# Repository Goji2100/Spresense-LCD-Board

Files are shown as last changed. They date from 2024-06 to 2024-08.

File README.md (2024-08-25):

# Spresense-LCD-Board
## LCD board for Spresense
Spresenseの拡張ボードにスタックするLCDボードです
<br>

## 表示画面
<table>
<tr>
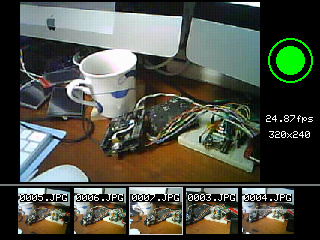
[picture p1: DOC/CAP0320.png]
<td></td>
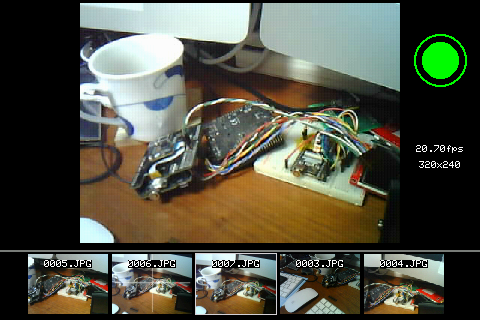
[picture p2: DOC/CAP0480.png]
<td></td>
</tr>
<tr>
<td>表示画面（480 x 320）</td>
<td>表示画面（320 x 240）</td>
</tr>
</table>
<br>

## 組み立て完成写真
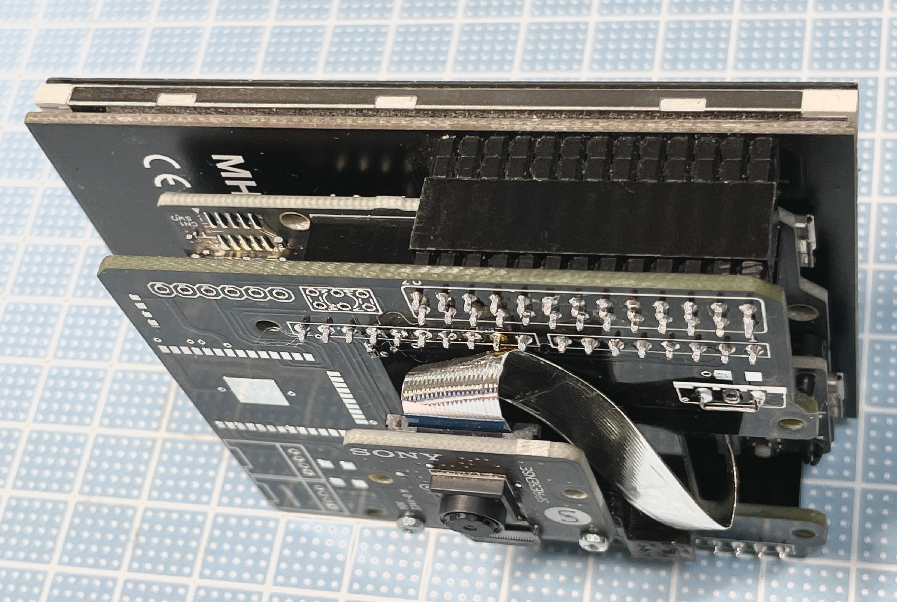
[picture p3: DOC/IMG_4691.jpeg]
<br><br>

## LCDボードとSpresense拡張ボード
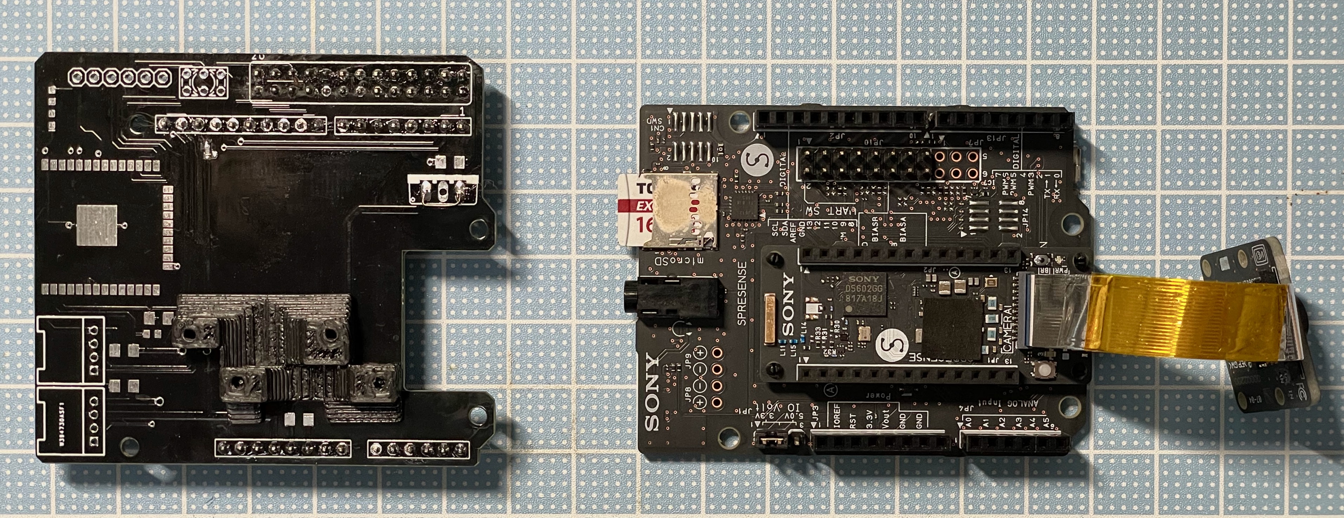
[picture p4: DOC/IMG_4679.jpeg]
<br><br>

## LCDボード回路図
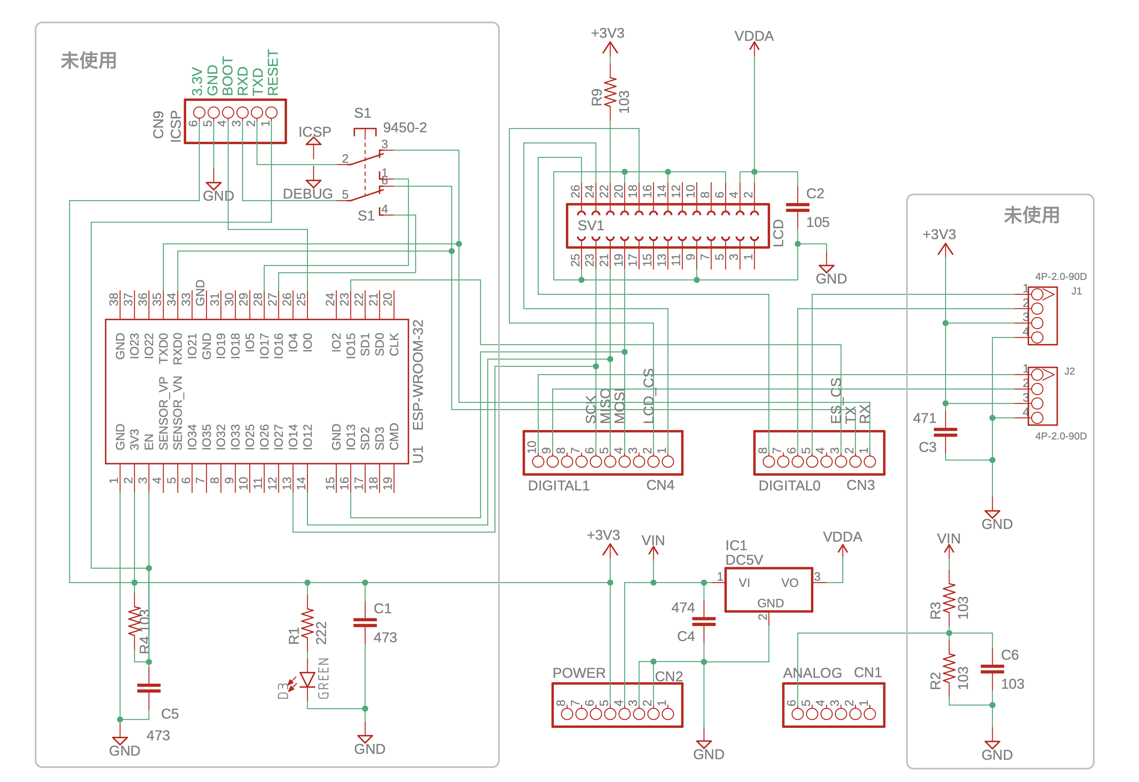
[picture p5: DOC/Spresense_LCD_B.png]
<br><br>

## 使用するLCD


左）3.5 インチタッチスクリーン MHS TFT LCD モジュール[SPI 125MHz Support]<br>
右）GeeekPi 3.5インチ320 * 480モニタータッチパネル LCD[SPI 180MHz Support]　　
<br>
<br>
<br>

## その他のLCD
<table>
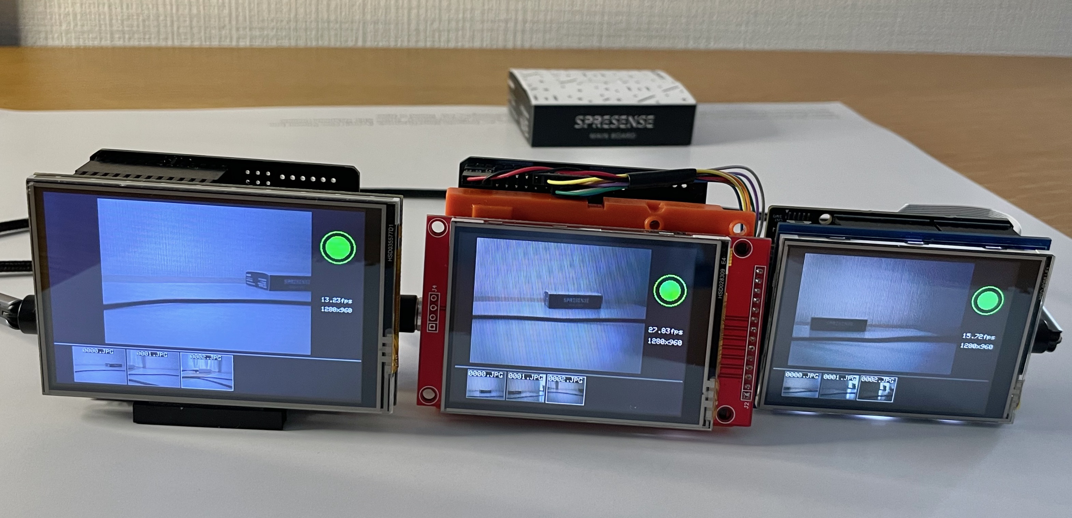
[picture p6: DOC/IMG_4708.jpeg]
<tr><td></td></tr>
</table>
<br>

### Adafruit ILI9341
<table>
<tr>
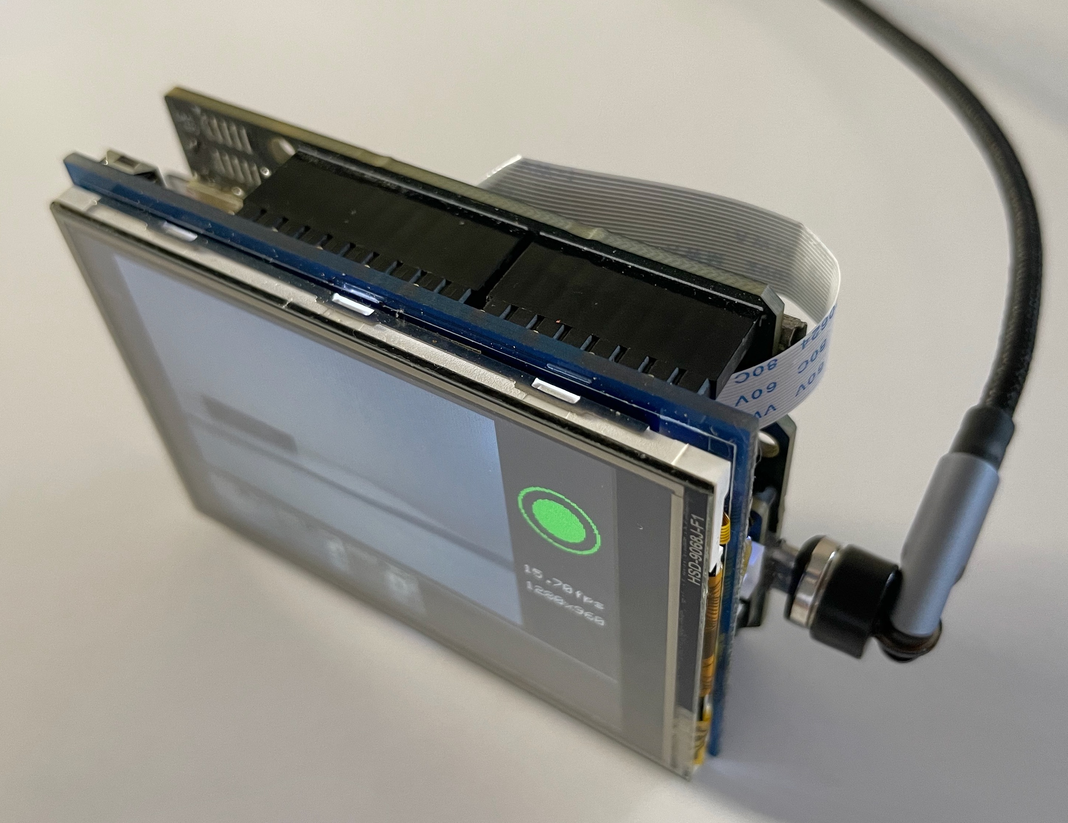
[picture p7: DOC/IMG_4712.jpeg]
<td></td>
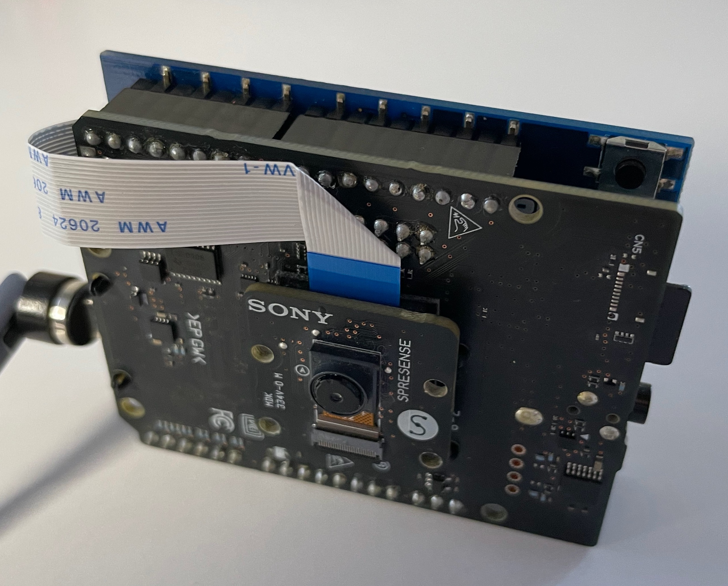
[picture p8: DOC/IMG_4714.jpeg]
<td></td>
</tr>
<tr>
<td>Adafruit ILI9341（表面） 320 x 240</td>
<td>Adafruit ILI9341（背面）</td>
</tr>
</table>

### Adafruit ILI9341 の組み込み
<table>
<tr>
<td></td>
</tr>
<tr>
<td>フラットケーブルの折り曲げ加工、ILI9341の改造（TFT_CSをpin6に変更する）</td>
</tr>
</table>
<table>
<tr>
<td></td>
</tr>
<tr>
<td>フラットケーブル取り付け、動作電圧の変更（Shieldは５V動作）</td>
</tr>
</table>
<table>
<tr>
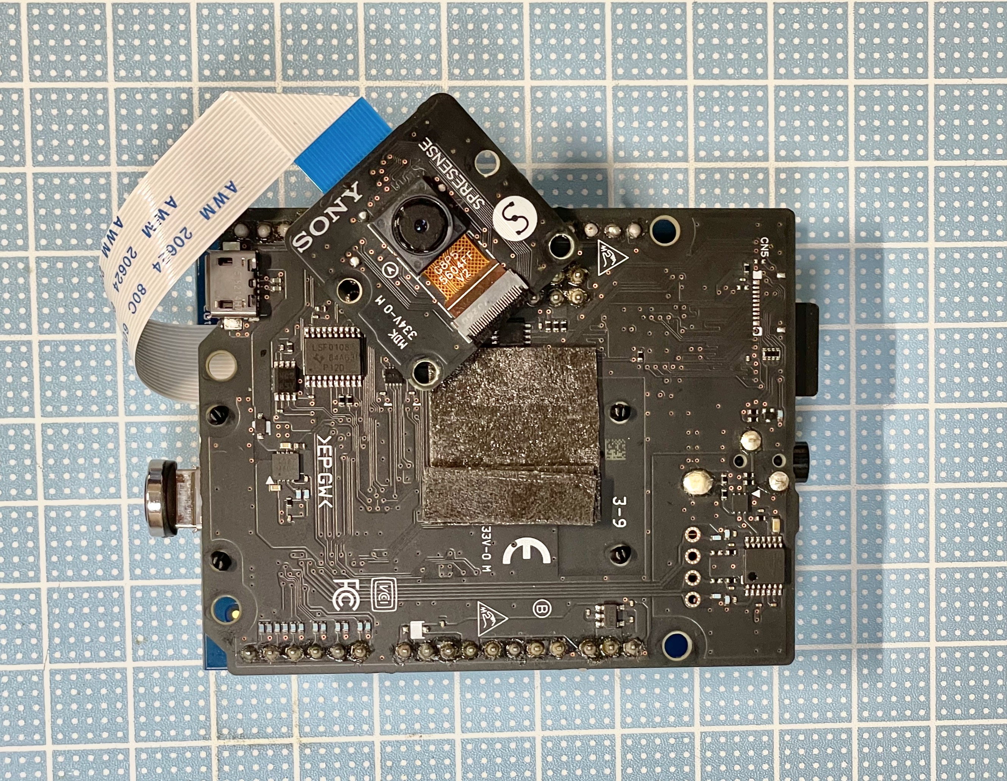
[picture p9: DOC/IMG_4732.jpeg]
<td></td>
</tr>
<tr>
<td>カメラは拡張ボードの背面に両面テープで貼り付け💦</td>
</tr>
</table>
<br>

### ILI9341(320 x 240)/ILI9488(480 x 320)
<table>
<tr>
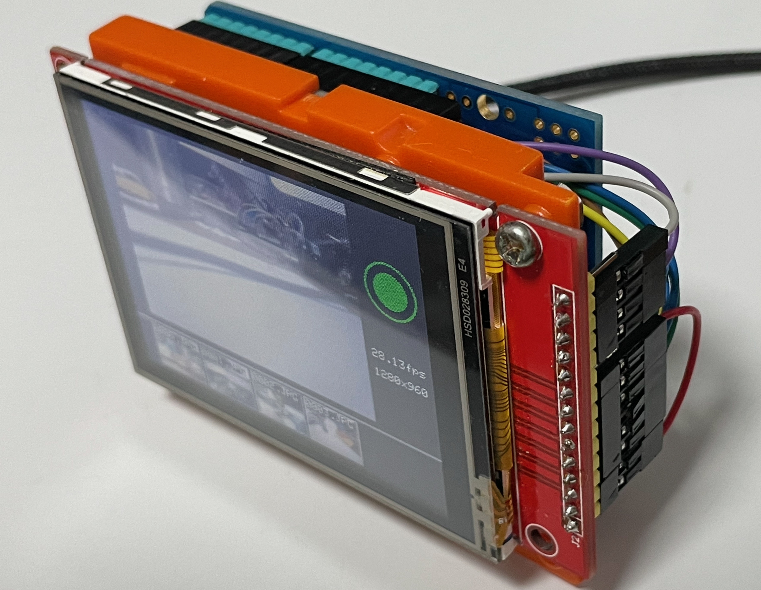
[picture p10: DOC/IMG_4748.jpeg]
<td></td>
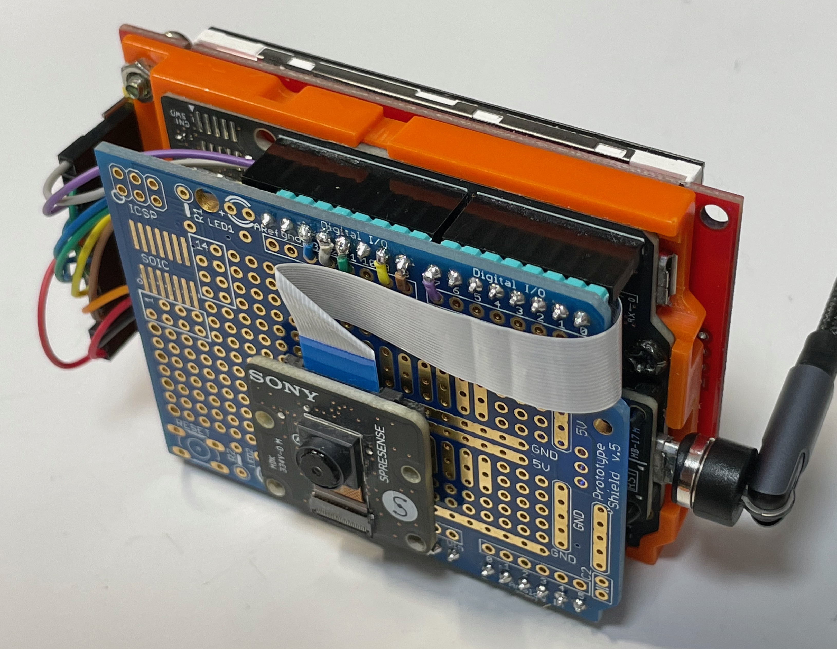
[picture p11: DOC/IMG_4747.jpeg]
<td></td>
</tr>
<tr>
<td>ILI9341（表面） 320 x 240</td>
<td>ILI9341（背面）</td>
</tr>
</table>
<br>

### ILI9341/ILI9488 の組み込み
<table>
<tr>
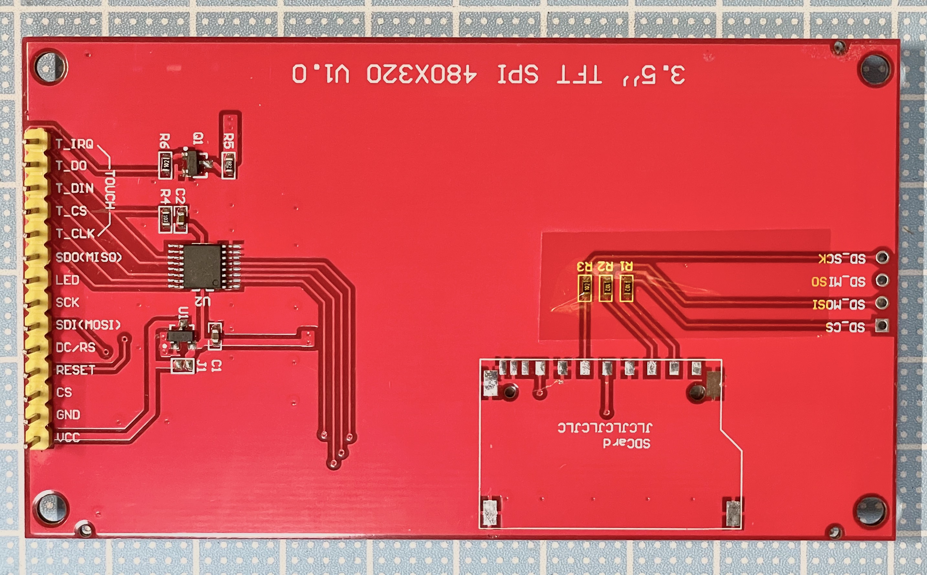
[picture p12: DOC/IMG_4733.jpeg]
<td></td>
<td></td>
</tr>
<tr>
<td>ILI9488（ILI9341とピン配置は同じ）</td>
<td>ILI9341/ILI9488と拡張ボードとの配線</td>
</tr>
</table>
<br>

<table>
<tr>
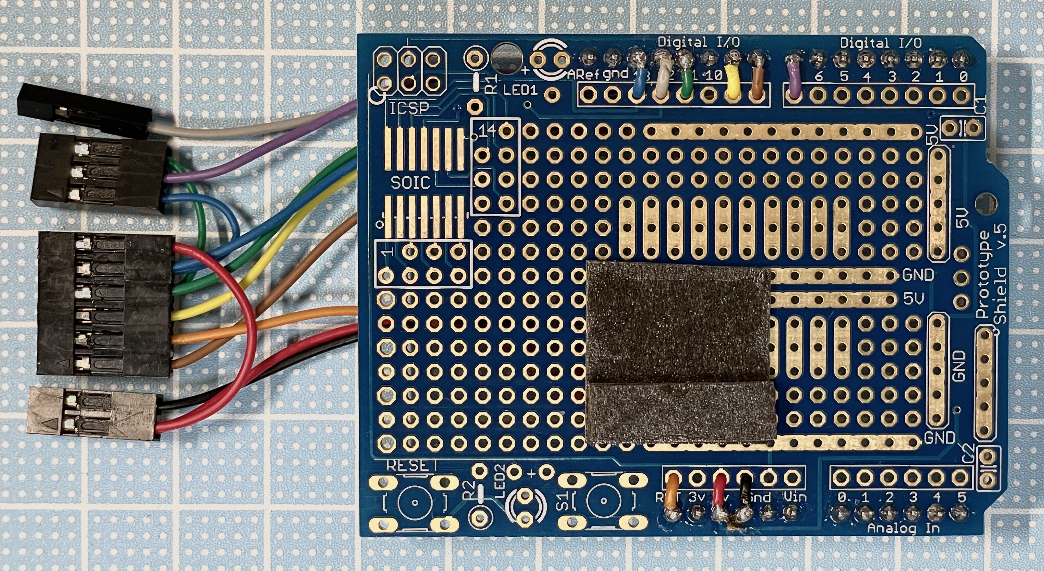
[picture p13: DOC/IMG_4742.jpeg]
<td></td>
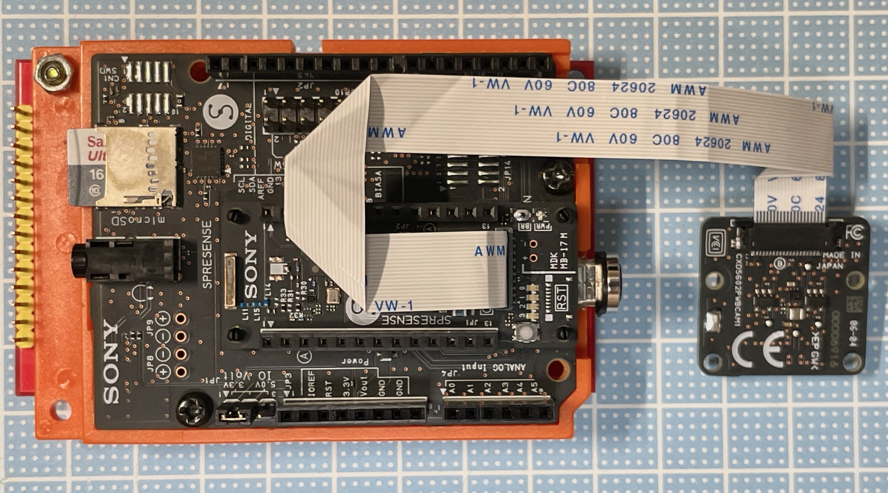
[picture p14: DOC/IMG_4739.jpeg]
<td></td>
</tr>
<tr>
<td>実際の配線（ProtoType Shieldを経由します）</td>
<td>カメラフラットケーブルの折り曲げ加工</td>
</tr>
</table>
<br>

### ILI9486(480 x 320)
<table>
<tr>
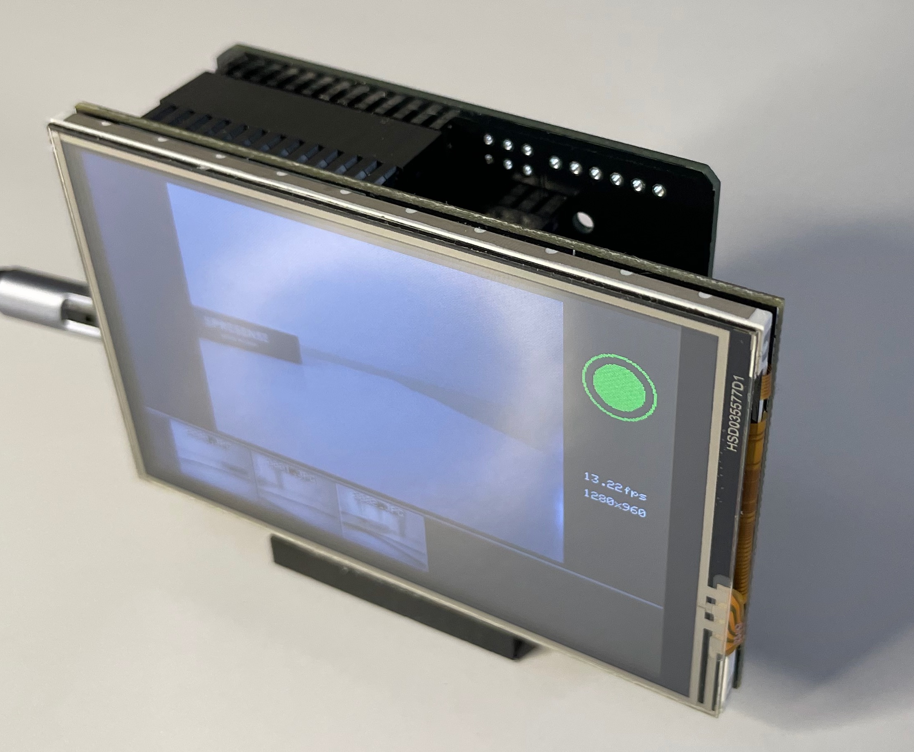
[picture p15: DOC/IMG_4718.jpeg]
<td></td>
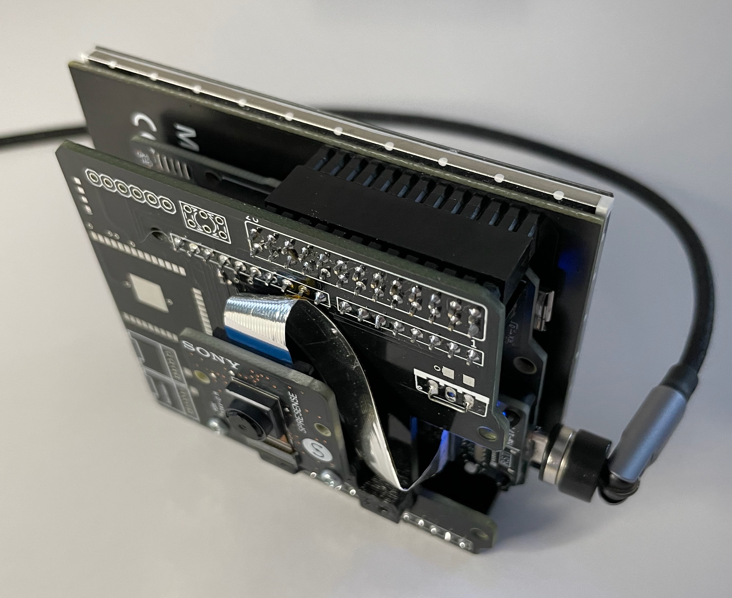
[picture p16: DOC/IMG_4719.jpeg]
<td></td>
</tr>
<tr>
<td>ILI9486（表面） 480 x 320</td>
<td>ILI9486（裏面）</td>
</tr>
</table>
<br>

## ILI9486の組み込み
### - ピンヘッダー５組
### - プルアップ抵抗（10kΩ）
### - 電源シュートジャンパーを半田付け
### - カメラをカメラマウンターに取り付け<br><br>
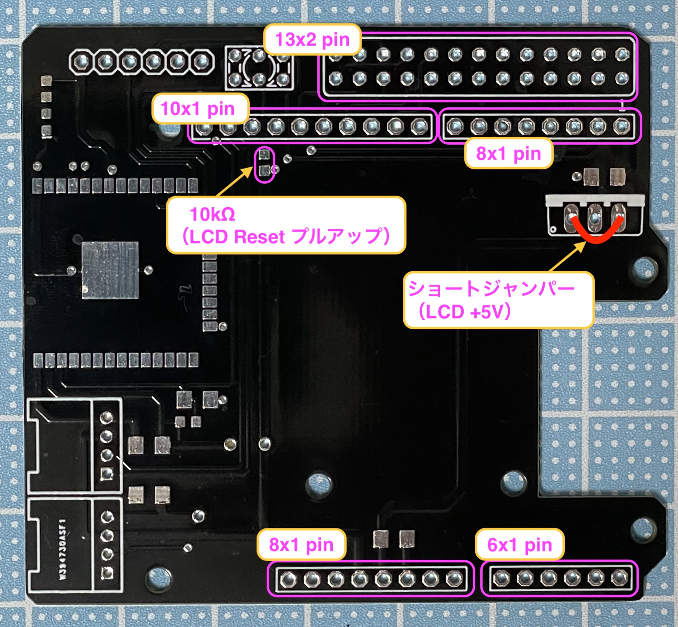
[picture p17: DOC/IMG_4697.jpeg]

<br>
<br>

### カメラマウンター<br>
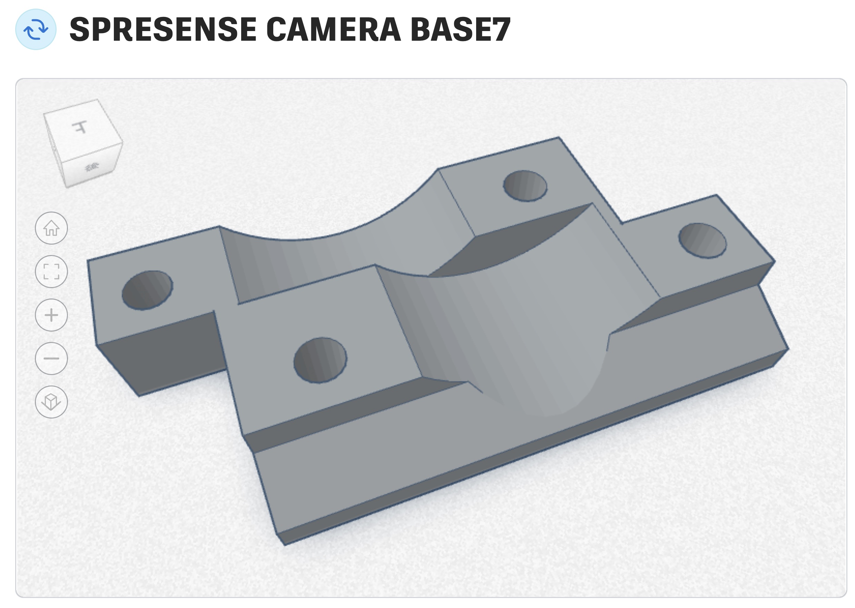
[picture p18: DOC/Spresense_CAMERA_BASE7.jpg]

#### [カメラマウンター] DOC/SPRESENSE CAMERA BASE7.stl <br>
#### [カメラマウンター　Tinkercad](https://www.tinkercad.com/things/2FAODkR43Zt-spresense-camera-base7)
<br><br>

## ビルド
1. フォルダ（camera_apitest）をArduinoスケッチフォルダーにコピー
2. ボードパッケージは "2.6.0" を使用します（3.xでは問題あり）
3. Memory:1536KBを選択
4. ライブラリーに "LovyanGFX(1.1.9)" と "XPT2046_Touchscreen" をインストール
5. Adafruit ILI9341のタッチパネルを使用する場合は "Adafruit_STMPE610" もインストール
6. ビルドしてアップロード

### define 文の変更（使用するLCDを選択）
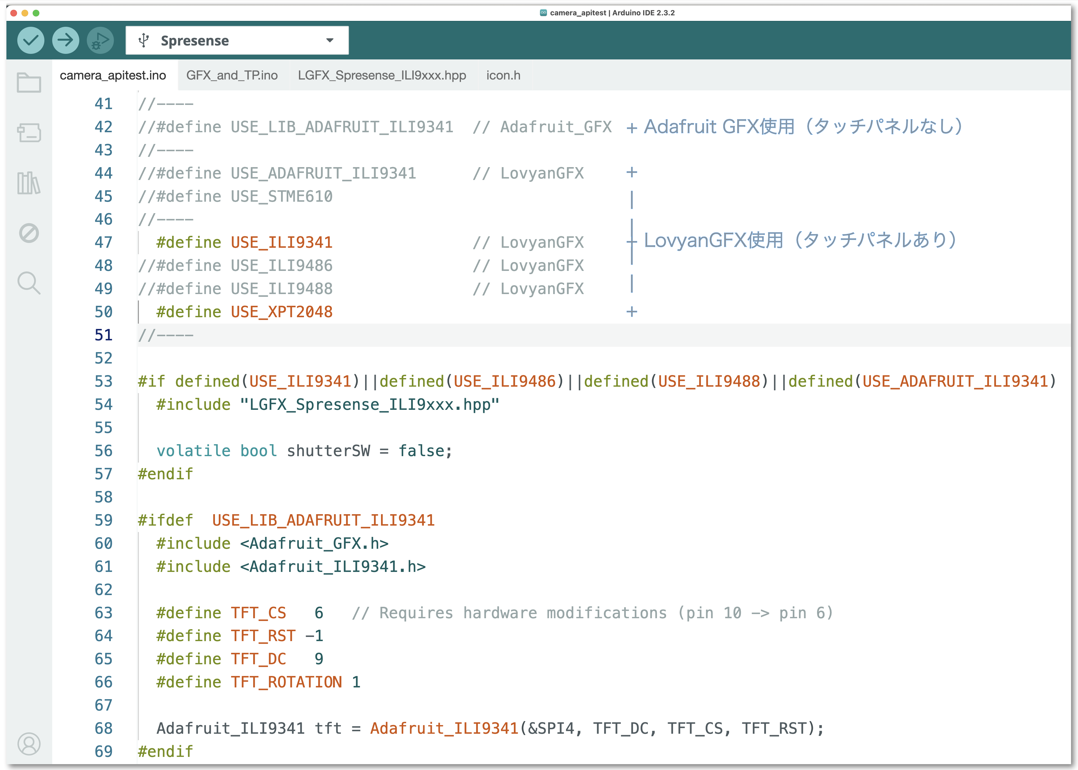
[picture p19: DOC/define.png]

<br><br>

## 使用方法
- オリジナルはSpresenseのサンプルスケッチ->camera->camera_apitest.inoです<br>
  LovyanGFXでプレビュー表示するする処理を追加<br>
  タッチパネル読み取り処理を追加<br>
  オリジナルにあるSerialターミナルでのメニュー操作はそのままです<br>
  （写真の解像度、ISO感度などの設定、撮影画像のSDへの保存などができます）<br>
- タッチパネルによる写真撮影処理を追加
- 撮影した写真のサムネイル表示処理を追加（最新の5枚まで表示）
<br><br>
## ライセンス
[LovyanGFX](https://github.com/lovyan03/LovyanGFX/tree/master) [FreeBSD](https://github.com/lovyan03/LovyanGFX/blob/master/license.txt) lovyan03
<br>
[camera_apitest.ino]() [GNU]() Sony Semiconductor Solutions Corporation
<br>

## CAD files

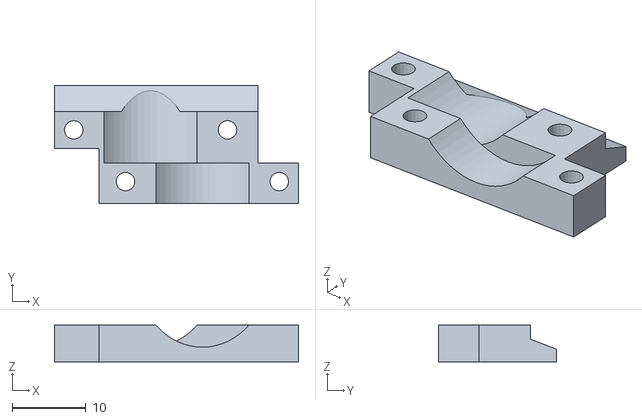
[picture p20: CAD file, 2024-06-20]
DOC/SPRESENSE CAMERA BASE7.stl
33.0 x 15.9 x 5.00

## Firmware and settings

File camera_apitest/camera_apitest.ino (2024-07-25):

/*
 *  camera_apitest.ino - Advanced camera API example sketch
 *  Copyright 2022 Sony Semiconductor Solutions Corporation
 *
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
 *  This is a test app for the camera library.
 *  This library can only be used on the Spresense with the FCBGA chip package.
 */

/****************************************************************************
 * Included Files
 ****************************************************************************/

#include <Camera.h>
#include <SDHCI.h>
#include <RTC.h>


/****************************************************************************
 * LCD preview option
 ****************************************************************************/

/* Use Adafruit_ILI9341 library and Adafruit-GFX-Library
 * Please see Spresense Arduino Tutorial for more details.
 * https://developer.sony.com/develop/spresense/docs/arduino_tutorials_ja.html
 */

//----
//#define USE_LIB_ADAFRUIT_ILI9341  // Adafruit_GFX
//----
//#define USE_ADAFRUIT_ILI9341      // LovyanGFX
//#define USE_STME610
//----
  #define USE_ILI9341               // LovyanGFX
//#define USE_ILI9486               // LovyanGFX
//#define USE_ILI9488               // LovyanGFX
  #define USE_XPT2048
//----

#if defined(USE_ILI9341)||defined(USE_ILI9486)||defined(USE_ILI9488)||defined(USE_ADAFRUIT_ILI9341) 
  #include "LGFX_Spresense_ILI9xxx.hpp"

  volatile bool shutterSW = false;
#endif

#ifdef  USE_LIB_ADAFRUIT_ILI9341
  #include <Adafruit_GFX.h>
  #include <Adafruit_ILI9341.h>

  #define TFT_CS   6   // Requires hardware modifications (pin 10 -> pin 6)
  #define TFT_RST -1
  #define TFT_DC   9
  #define TFT_ROTATION 1

  Adafruit_ILI9341 tft = Adafruit_ILI9341(&SPI4, TFT_DC, TFT_CS, TFT_RST);
#endif

/****************************************************************************
 * Initial parameters
 ****************************************************************************/
SDClass  theSD;
int               g_pict_id = 0;
int               g_width   = CAM_IMGSIZE_QUADVGA_H;
int               g_height  = CAM_IMGSIZE_QUADVGA_V;
CAM_IMAGE_PIX_FMT g_img_fmt = CAM_IMAGE_PIX_FMT_JPG;
CAM_WHITE_BALANCE g_wb      = CAM_WHITE_BALANCE_AUTO;
CAM_COLOR_FX      g_cfx     = CAM_COLOR_FX_NONE;
bool              g_awb     = true;
bool              g_ae      = true;
int               g_divisor = 7;

/****************************************************************************
 * Print error message
 ****************************************************************************/
void printError(enum CamErr err)
{
  Serial.print("Error: ");
  switch (err) {
  case CAM_ERR_NO_DEVICE:             Serial.println("No Device");                     break;
  case CAM_ERR_ILLEGAL_DEVERR:        Serial.println("Illegal device error");          break;
  case CAM_ERR_ALREADY_INITIALIZED:   Serial.println("Already initialized");           break;
  case CAM_ERR_NOT_INITIALIZED:       Serial.println("Not initialized");               break;
  case CAM_ERR_NOT_STILL_INITIALIZED: Serial.println("Still picture not initialized"); break;
  case CAM_ERR_CANT_CREATE_THREAD:    Serial.println("Failed to create thread");       break;
  case CAM_ERR_INVALID_PARAM:         Serial.println("Invalid parameter");             break;
  case CAM_ERR_NO_MEMORY:             Serial.println("No memory");                     break;
  case CAM_ERR_USR_INUSED:            Serial.println("Buffer already in use");         break;
  case CAM_ERR_NOT_PERMITTED:         Serial.println("Operation not permitted");       break;
  default:
    break;
  }
}

/****************************************************************************
 * Callback from Camera library when video frame is captured.
 ****************************************************************************/
void CamCB(CamImage img)
{
  /* Check the img instance is available or not. */
  if (img.isAvailable()) {
    #ifdef USE_LIB_ADAFRUIT_ILI9341
      /* If you want RGB565 data, convert image data format to RGB565 */
      img.convertPixFormat(CAM_IMAGE_PIX_FMT_RGB565);

      /* You can use image data directly by using getImgSize() and getImgBuff().
       * for displaying image to a display, etc. */
      tft.drawRGBBitmap(0, 0, (uint16_t *)img.getImgBuff(), 320, 240);
    #endif

    #if defined(USE_LovyanGFX)
      tft.setSwapBytes(true);
      tft.pushImage(Z2_px, Z2_py, img.getWidth(), img.getHeight(), (uint16_t *)img.getImgBuff());
      tft.setSwapBytes(false);
      displayFPS(0);
      #if defined(USE_XPT2048)||defined(USE_STME610)
        if (shutterSW) getShutter(); else shutterSW = getShutter(); 
      #endif
    #endif

  } else {
    Serial.println("Failed to get video stream image");
  }
}

/****************************************************************************
 * setup
 ****************************************************************************/
void setup()
{
  CamErr err;

  Serial.begin(115200);

  /* Set compiled datetime to RTC temporarily */
  RTC.begin();
  RtcTime compiledDateTime(__DATE__, __TIME__);
  RTC.setTime(compiledDateTime);

  #ifdef USE_LIB_ADAFRUIT_ILI9341
    /* Initialize TFT */
    tft.begin();
    tft.setRotation(TFT_ROTATION);
  #endif

  #if defined(USE_LovyanGFX)
    tftTPinit();
  #endif

  /* Initialize SD */
  while (!theSD.begin()) {
    /* wait until SD card is mounted. */
    Serial.println("Insert SD card.");
    sleep(1);
  }

  /* begin() without parameters means that
   * number of buffers = 1, 30FPS, QVGA, YUV 4:2:2 format */

  Serial.println("Prepare camera");

  #ifdef USE_LIB_ADAFRUIT_ILI9341
  err = theCamera.begin();
  if (err != CAM_ERR_SUCCESS) {
    printError(err);
  }
  #endif

  #if defined(USE_ILI9341)||defined(USE_ADAFRUIT_ILI9341)
    err = theCamera.begin(2, CAM_VIDEO_FPS_60, 240, 180, CAM_IMAGE_PIX_FMT_RGB565, 7);
  #else
    err = theCamera.begin(2, CAM_VIDEO_FPS_60, CAM_IMGSIZE_QVGA_H,  CAM_IMGSIZE_QVGA_V,  CAM_IMAGE_PIX_FMT_RGB565, 7);
    if (err != CAM_ERR_SUCCESS) {
      printError(err);
    }
  #endif

  /* Start video stream. */

  Serial.println("Start streaming");
  err = theCamera.startStreaming(true, CamCB);
  if (err != CAM_ERR_SUCCESS) {
    printError(err);
  }

  /* Set parameters about still picture. */

  Serial.println("Set still picture format");
  err = theCamera.setStillPictureImageFormat(g_width, g_height,
                                             g_img_fmt, g_divisor);
  if (err != CAM_ERR_SUCCESS) {
    printError(err);
  }
}

/****************************************************************************
 * Get the input string from serial monitor
 ****************************************************************************/
String inputString()
{
  String input;

  do {

    #if defined(USE_XPT2048)||defined(USE_STME610)
      if (shutterSW) {
        input = "P";
        break;
      }
    #endif

    if (Serial.available() > 0 ) {
      input = Serial.readStringUntil('\n');
      input.toUpperCase();
      input.trim();
    } else delay(20);
  } while (0 == input.length());
  return input;
}

/****************************************************************************
 * API: getHDR()
 ****************************************************************************/
void showHDR()
{
  CAM_HDR_MODE hdr = theCamera.getHDR();

  Serial.print("HDR          : ");
  switch (hdr) {
  case CAM_HDR_MODE_OFF:  Serial.println("Off");   break;
  case CAM_HDR_MODE_AUTO: Serial.println("Auto");  break;
  case CAM_HDR_MODE_ON:   Serial.println("On");    break;
  default:                Serial.println("Error"); break;
  }
}

/****************************************************************************
 * API: setHDR()
 ****************************************************************************/
void menuHDR()
{
  CamErr err;
  String input;
  CAM_HDR_MODE mode;

  while (1) {
    showHDR();
    Serial.println();
    Serial.println("--- HDR Menu ---");
    Serial.println("0: Off");
    Serial.println("1: Auto");
    Serial.println("2: On");
    Serial.println("X: exit");
    Serial.println();

    input = inputString();

    if      (input == "0") { mode = CAM_HDR_MODE_OFF;  }
    else if (input == "1") { mode = CAM_HDR_MODE_AUTO; }
    else if (input == "2") { mode = CAM_HDR_MODE_ON;   }
    else                   { return; }

    err = theCamera.setHDR(mode);

    if (err != CAM_ERR_SUCCESS) {
      printError(err);
    }
  }
}

/****************************************************************************
 * Show AWB current settings
 ****************************************************************************/
void showAWB()
{
  Serial.printf("AWB          : %s\n", g_awb ? "On" : "Off");

  Serial.print("AWB mode     : ");
  switch (g_wb) {
  case CAM_WHITE_BALANCE_AUTO:         Serial.println("Automatic");    break;
  case CAM_WHITE_BALANCE_INCANDESCENT: Serial.println("Incandescent"); break;
  case CAM_WHITE_BALANCE_FLUORESCENT:  Serial.println("Fluorescent");  break;
  case CAM_WHITE_BALANCE_DAYLIGHT:     Serial.println("Daylight");     break;
  case CAM_WHITE_BALANCE_FLASH:        Serial.println("Flash");        break;
  case CAM_WHITE_BALANCE_CLOUDY:       Serial.println("Cloudy");       break;
  case CAM_WHITE_BALANCE_SHADE:        Serial.println("Shade");        break;
  default:
    break;
  }
}

/****************************************************************************
 * API: setAutoWhiteBalance(), setAutoWhiteBalanceMode()
 ****************************************************************************/
void menuAWB()
{
  CamErr err;
  String input;
  bool awb = g_awb;
  CAM_WHITE_BALANCE wb = g_wb;

  while (1) {
    showAWB();
    Serial.println();
    Serial.println("--- Auto WhiteBlance Menu ---");
    Serial.println("Y: On");
    Serial.println("N: Off");
    Serial.println("0: Automatic");
    Serial.println("1: Incandescent");
    Serial.println("2: Fluorescent");
    Serial.println("3: Daylight");
    Serial.println("4: Flash");
    Serial.println("5: Cloudy");
    Serial.println("6: Shade");
    Serial.println("X: exit");
    Serial.println();

    input = inputString();

    if ((input == "Y") || (input == "N")) {
      if      (input == "Y") { Serial.println("On");  awb = true;  }
      else if (input == "N") { Serial.println("Off"); awb = false; }

      err = theCamera.setAutoWhiteBalance(awb);

    } else {
      if      (input == "0") { Serial.println("Automatic");    wb = CAM_WHITE_BALANCE_AUTO;         }
      else if (input == "1") { Serial.println("Incandescent"); wb = CAM_WHITE_BALANCE_INCANDESCENT; }
      else if (input == "2") { Serial.println("Fluorescent");  wb = CAM_WHITE_BALANCE_FLUORESCENT;  }
      else if (input == "3") { Serial.println("Daylight");     wb = CAM_WHITE_BALANCE_DAYLIGHT;     }
      else if (input == "4") { Serial.println("Flash");        wb = CAM_WHITE_BALANCE_FLASH;        }
      else if (input == "5") { Serial.println("Cloudy");       wb = CAM_WHITE_BALANCE_CLOUDY;       }
      else if (input == "6") { Serial.println("Shade");        wb = CAM_WHITE_BALANCE_SHADE;        }
      else { return; }

      err = theCamera.setAutoWhiteBalanceMode(wb);
    }

    if (err != CAM_ERR_SUCCESS) {
      printError(err);
    } else {
      g_awb = awb;
      g_wb = wb;
    }
  }
}

/****************************************************************************
 * Show Color Effect current setting
 ****************************************************************************/
void showCFX()
{
  Serial.print("Color Effect : ");
  switch (g_cfx) {
  case CAM_COLOR_FX_NONE:         Serial.println("No effect");         break;
  case CAM_COLOR_FX_BW:           Serial.println("Black/white");       break;
  case CAM_COLOR_FX_SEPIA:        Serial.println("Sepia");             break;
  case CAM_COLOR_FX_NEGATIVE:     Serial.println("Pos/Neg inversion"); break;
  case CAM_COLOR_FX_SKETCH:       Serial.println("Sketch");            break;
  case CAM_COLOR_FX_VIVID:        Serial.println("Vivid");             break;
  case CAM_COLOR_FX_SOLARIZATION: Serial.println("Solarization");      break;
  case CAM_COLOR_FX_PASTEL:       Serial.println("Pastel");            break;
  default:
    break;
  }
}

/****************************************************************************
 * API: setColorEffect()
 ****************************************************************************/
void menuCFX()
{
  CamErr err;
  String input;
  CAM_COLOR_FX cfx;

  while (1) {
    showCFX();
    Serial.println();
    Serial.println("--- Color Effect Menu ---");
    Serial.println("0 : No effect");
    Serial.println("1 : Black/white");
    Serial.println("2 : Sepia");
    Serial.println("3 : Positive/Negative inversion");
    Serial.println("4 : Sketch");
    Serial.println("5 : Vivid");
    Serial.println("6 : Solarization");
    Serial.println("7 : Pastel");
    Serial.println("X : exit");
    Serial.println();

    input = inputString();

    if      (input == "0") { Serial.println("No effect");         cfx = CAM_COLOR_FX_NONE;         }
    else if (input == "1") { Serial.println("Black/white");       cfx = CAM_COLOR_FX_BW;           }
    else if (input == "2") { Serial.println("Sepia");             cfx = CAM_COLOR_FX_SEPIA;        }
    else if (input == "3") { Serial.println("Pos/Neg inversion"); cfx = CAM_COLOR_FX_NEGATIVE;     }
    else if (input == "4") { Serial.println("Sketch");            cfx = CAM_COLOR_FX_SKETCH;       }
    else if (input == "5") { Serial.println("Vivid");             cfx = CAM_COLOR_FX_VIVID;        }
    else if (input == "6") { Serial.println("Solarization");      cfx = CAM_COLOR_FX_SOLARIZATION; }
    else if (input == "7") { Serial.println("Pastel");            cfx = CAM_COLOR_FX_PASTEL;       }
    else { return; }

    err = theCamera.setColorEffect(cfx);

    if (err != CAM_ERR_SUCCESS) {
      printError(err);
    } else {
      g_cfx = cfx;
    }
  }
}

/****************************************************************************
 * API: getAbsoluteExposure()
 ****************************************************************************/
void showAE()
{
  int32_t time = theCamera.getAbsoluteExposure();

  Serial.printf("AE           : %s\n", g_ae ? "Auto" : "Manual");
  Serial.printf("AE time      : %ld [100us]\n", time);
}

/****************************************************************************
 * API: setAutoExposure(), setAbsoluteExposure()
 ****************************************************************************/
void menuAE()
{
  CamErr err;
  String input;
  bool ae = g_ae;

  while (1) {
    showAE();
    Serial.println();
    Serial.println("--- AE Menu ---");
    Serial.println("A : Auto");
    Serial.println("M : Manual");
    Serial.println("1~: Exposure time [100usec]");
    Serial.println("G : get");
    Serial.println("X : exit");
    Serial.println();

    input = inputString();

    if ((input == "A") || (input == "M")) {
      if      (input == "A") { Serial.println("Auto");   ae = true;  }
      else if (input == "M") { Serial.println("Manual"); ae = false; }

      err = theCamera.setAutoExposure(ae);

    } else if (input == "G") {
      continue;
    } else if (isDigit(input.charAt(0))) {
      long value = input.toInt();

      err = theCamera.setAbsoluteExposure(value);
      ae = false;
    } else {
      return;
    }

    if (err != CAM_ERR_SUCCESS) {
      printError(err);
    } else {
      g_ae = ae;
    }

    /* If AE is changed, it takes time for the value to take effect. */
    delay(250);

  }
}

/****************************************************************************
 * API: getISOSensitivity()
 ****************************************************************************/
void showISO()
{
  int32_t iso = theCamera.getISOSensitivity();

  Serial.printf("ISO          : %ld\n", iso / 1000);
}

/****************************************************************************
 * API: setISOSensitivity()
 ****************************************************************************/
void menuISO()
{
  CamErr err;
  String input;

  while (1) {
    showISO();
    Serial.println();
    Serial.println("--- ISO Menu ---");
    Serial.println("A   : Auto");
    Serial.println("N   : Off");
    Serial.println("25  : ISO Sensitivity 25");
    Serial.println("32  : ISO Sensitivity 32");
    Serial.println("40  : ISO Sensitivity 40");
    Serial.println("50  : ISO Sensitivity 50");
    Serial.println("64  : ISO Sensitivity 64");
    Serial.println("80  : ISO Sensitivity 80");
    Serial.println("100 : ISO Sensitivity 100");
    Serial.println("125 : ISO Sensitivity 125");
    Serial.println("160 : ISO Sensitivity 160");
    Serial.println("200 : ISO Sensitivity 200");
    Serial.println("250 : ISO Sensitivity 250");
    Serial.println("320 : ISO Sensitivity 320");
    Serial.println("400 : ISO Sensitivity 400");
    Serial.println("500 : ISO Sensitivity 500");
    Serial.println("640 : ISO Sensitivity 640");
    Serial.println("800 : ISO Sensitivity 800");
    Serial.println("1000: ISO Sensitivity 1000");
    Serial.println("1250: ISO Sensitivity 1250");
    Serial.println("1600: ISO Sensitivity 1600");
    Serial.println("G   : get");
    Serial.println("X   : exit");
    Serial.println();

    input = inputString();

    if      (input == "A") { err = theCamera.setAutoISOSensitivity(true);  }
    else if (input == "N") { err = theCamera.setAutoISOSensitivity(false); }
    else if (input == "G") { continue; }
    else if (isDigit(input.charAt(0))) {
      int value = (int)input.toInt();
      err = theCamera.setISOSensitivity(value * 1000);
    } else {
      return;
    }

    if (err != CAM_ERR_SUCCESS) {
      printError(err);
    }

    /* If AE is changed, it takes time for the value to take effect. */
    delay(250);

  }
}

/****************************************************************************
 * API: setStillPictureImageFormat(img_fmt)
 ****************************************************************************/
void menuFormat()
{
  CamErr err;
  String input;
  CAM_IMAGE_PIX_FMT fmt;

  while (1) {
    showFormat();
    Serial.println();
    Serial.println("--- Format Menu ---");
    Serial.println("RGB : RGB565");
    Serial.println("YUV : YUV422");
    Serial.println("JPG : JPEG");
    Serial.println("X   : exit");
    Serial.println();

    input = inputString();

    if      (input == "RGB") { fmt = CAM_IMAGE_PIX_FMT_RGB565; }
    else if (input == "YUV") { fmt = CAM_IMAGE_PIX_FMT_YUV422; }
    else if (input == "JPG") { fmt = CAM_IMAGE_PIX_FMT_JPG;    }
    else {
      return;
    }

    err = theCamera.setStillPictureImageFormat(g_width, g_height,
                                               fmt, g_divisor);
    if (err != CAM_ERR_SUCCESS) {
      printError(err);
    } else {
      g_img_fmt = fmt;
    }
  }
}

/****************************************************************************
 * API: setStillPictureImageFormat(img_width, img_height)
 ****************************************************************************/
void menuResolution()
{
  CamErr err;
  String input;
  int width;
  int height;

  while (1) {
    showFormat();
    Serial.println();
    Serial.println("--- Image Size Menu ---");
    Serial.println("1  :        (96x64)");
    Serial.println("2  : QQVGA  (160x120)");
    Serial.println("3  : QVGA   (320x240)");
    Serial.println("4  : VGA    (640x480)");
    Serial.println("5  : HD     (1280x720)");
    Serial.println("6  : QUADVGA(1280x960)");
    Serial.println("7  : FULLHD (1920x1080)");
    Serial.println("8  : QXGA   (2048x1536)");
    Serial.println("9  : 5MP    (2560x1920)");
    Serial.println("X  : exit");
    Serial.println();

    input = inputString();

    if      (input == "1") { width = 96;                    height = 64;                    }
    else if (input == "2") { width = CAM_IMGSIZE_QQVGA_H;   height = CAM_IMGSIZE_QQVGA_V;   }
    else if (input == "3") { width = CAM_IMGSIZE_QVGA_H;    height = CAM_IMGSIZE_QVGA_V;    }
    else if (input == "4") { width = CAM_IMGSIZE_VGA_H;     height = CAM_IMGSIZE_VGA_V;     }
    else if (input == "5") { width = CAM_IMGSIZE_HD_H;      height = CAM_IMGSIZE_HD_V;      }
    else if (input == "6") { width = CAM_IMGSIZE_QUADVGA_H; height = CAM_IMGSIZE_QUADVGA_V; }
    else if (input == "7") { width = CAM_IMGSIZE_FULLHD_H;  height = CAM_IMGSIZE_FULLHD_V;  }
    else if (input == "8") { width = CAM_IMGSIZE_3M_H;      height = CAM_IMGSIZE_3M_V;      }
    else if (input == "9") { width = CAM_IMGSIZE_5M_H;      height = CAM_IMGSIZE_5M_V;      }
    else {
      return;
    }

    /* Adjust the divisor until buffer is allocated. */
    while (1) {
      err = theCamera.setStillPictureImageFormat(width, height,
                                                 g_img_fmt, g_divisor);
      if (err == CAM_ERR_NO_MEMORY) {
        g_divisor++;
      } else {
        break;
      }
    }

    if (err != CAM_ERR_SUCCESS) {
      printError(err);
    } else {
      g_width  = width;
      g_height = height;
      #if defined(USE_LovyanGFX)
        dispPictureSize(g_width, g_height);
      #endif
    }
  }
}
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
void loop()
{
  menuTop();
}

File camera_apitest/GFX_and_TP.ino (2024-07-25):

// -----------------------------------------------------------------------------
#if defined(USE_LovyanGFX)
void tftTPinit() {

  tft.begin();
  tft.setRotation(TFT_ROTATION);
  tft.fillScreen(TFT_BLACK);

  #if defined(USE_XPT2048)||defined(USE_STME610)
    TP.begin();
    #if defined(USE_XPT2048)
      TP.setRotation(1);
    #endif

    #if (0) // for ILI9486
      tft.drawBitmap(344, 144, ICON_heart  ,  36, 32, TFT_PINK);
      uint16_t px, py;
      while(!getTouch(&px, &py));
      if (px < tft.width() / 2) {
        tft.setRotation(5);
        tft.fillScreen(TFT_BLACK);
        tft.drawBitmap(344, 144, ICON_heart  ,  36, 32, TFT_PINK);
        while( getTouch(&px, &py));
        while(!getTouch(&px, &py));
      }
      tft.fillScreen(TFT_BLACK);
    #endif

    drawShutter(TFT_GREEN);
  
  #endif

  dispPictureSize(g_width, g_height);
  tft.fillRect(Z4_px, Z4_py, tft.width(), 2, TFT_DARKGREY);

}
#endif

#if defined(USE_XPT2048)||defined(USE_STME610)
void drawShutter(uint16_t color) {
  int sizeup = (Z3_px > 320) ? 4 : 0;

  tft.fillCircle(Z3_px + (Z3_pw / 2), 60, 22 + sizeup, color);
  tft.fillCircle(Z3_px + (Z3_pw / 2), 60, 20 + sizeup, TFT_BLACK);
  tft.fillCircle(Z3_px + (Z3_pw / 2), 60, 14 + sizeup, color);
}
#endif

#if defined(USE_LovyanGFX)||defined(USE_LIB_ADAFRUIT_ILI9341)
void displayFPS(size_t sw) {
  static volatile size_t loopCnt = 0;
  static uint64_t p_millis = millis();

  // Display Lap time
  loopCnt++;
  uint64_t lap_millis = (millis() - p_millis);

  if ((lap_millis >= 1000) && (sw == 0)) {
    float lap = ((float)lap_millis / loopCnt);
    float fps = (1000.0 / lap);
    drawFPS(fps);
    sw = 1;
  }

  if (sw == 1) {
    loopCnt = 0;
    p_millis = millis();
  }
}
#endif

// ---------------------------------------------------------
#if defined(USE_LovyanGFX)
void drawFPS(float fps) {
  char fpss[16];

  tft.setTextSize(1);
  tft.setTextColor(TFT_WHITE, TFT_BLACK);
  sprintf(fpss, (Z3_pw < 40) ? "%5.2f" : "%5.2ffps", fps);
  tft.drawCenterString(fpss,   Z3_px + (Z3_pw / 2), (Z3_ph / 2) + 20);
}

// ---------------------------------------------------------
void dispPictureSize(size_t dw, size_t dh) {
  char dwidth[32];

  sprintf(dwidth, "%dx%d", dw, dh);
  tft.setTextSize(1);
  tft.setTextColor(TFT_WHITE, TFT_BLACK);
  tft.fillRect(Z3_px, (Z3_ph / 2) + 36, Z3_pw, 8, TFT_BLACK);
  tft.drawCenterString(dwidth, Z3_px + (Z3_pw / 2), (Z3_ph / 2) + 36);
}

// ---------------------------------------------------------
#elif defined(USE_LIB_ADAFRUIT_ILI9341)
void drawFPS(float fps) {
  int x = (20 + 240 + (60 - (6 * 5)) / 2), y = 140 - (8 / 2);
  char fpss[16];

  sprintf(fpss, "%5.2f", fps);
  for (char *s = fpss; *s; s++, x+= 6) {
    tft.drawChar(x, y, *s, ILI9341_WHITE, ILI9341_BLACK, 1);
  }
}
#endif

// -----------------------------------------------------------------------------
#if defined(USE_LovyanGFX)
void makeThumb(CamImage *img, int g_pict_id) {
  static size_t spos = -1;
  char filename[32];

  #if defined(USE_ILI9486)||defined(USE_ILI9488)
  // Thumbnail
    #define THUMB_WW        ( 80)
    #define THUMB_HH        ( 60)
    #define Z4_tx           ((480 - (THUMB_WW + 4) * 5 - 4) / 2)

  #elif defined(USE_ILI9341)||defined(USE_ADAFRUIT_ILI9341)

  // Thumbnail
    #define THUMB_WW        ( 52)
    #define THUMB_HH        ( 40)
    #define Z4_tx           ((320 - (THUMB_WW + 4) * 5 - 4) / 2)
  #endif

  #define THUMB_POSX(n)     (Z4_tx + (n % 5) * (THUMB_WW + 4))
  #define THUMB_POSY()      (Z4_py + 4)

  tft.setTextSize(1);
  tft.setTextColor(TFT_WHITE, TFT_BLACK);

  if (spos >= 0)
    tft.drawRect(THUMB_POSX(spos++)    , THUMB_POSY()    , THUMB_WW + 2, THUMB_HH + 2, TFT_DARKGRAY );
  tft.drawRect  (THUMB_POSX(spos  )    , THUMB_POSY()    , THUMB_WW + 2, THUMB_HH + 2, TFT_LIGHTGREY);
  tft.fillRect  (THUMB_POSX(spos  ) + 1, THUMB_POSY() + 1, THUMB_WW    , THUMB_HH    , TFT_DARKGRAY );

  if (img->getPixFormat() == CAM_IMAGE_PIX_FMT_JPG) {  // JPEG format
    float zoomRatio;
    tft.setSwapBytes(true);
    if (((float)img->getWidth() / THUMB_WW) > ((float)img->getHeight() / THUMB_HH) )
      zoomRatio = ((float)THUMB_HH / img->getHeight());
    else
      zoomRatio = ((float)THUMB_WW / img->getWidth());
    int x = THUMB_POSX(spos) + 1, y = THUMB_POSY() + 1;
    tft.drawJpg(img->getImgBuff(), img->getImgSize(), x, y, THUMB_WW, THUMB_HH, 0, 0, zoomRatio, zoomRatio);
    tft.setSwapBytes(false);
  } else {
      tft.drawCenterString("X", THUMB_POSX(spos) + (THUMB_WW / 2), THUMB_POSY() + (THUMB_WW / 2));
  }

  sprintf(filename, "%04d.%s", g_pict_id,
        (img->getPixFormat() == CAM_IMAGE_PIX_FMT_RGB565) ? "RGB" :
        (img->getPixFormat() == CAM_IMAGE_PIX_FMT_YUV422) ? "YUV" :
        (img->getPixFormat() == CAM_IMAGE_PIX_FMT_JPG)    ? "JPG" :
        (img->getPixFormat() == CAM_IMAGE_PIX_FMT_GRAY)   ? "GRAY" : "NONE");
  tft.drawCenterString(filename, THUMB_POSX(spos) + (THUMB_WW / 2), THUMB_POSY() +  2);
}
#endif

// -----------------------------------------------------------------------------
#if defined(USE_XPT2048)||defined(USE_STME610)

#if defined(USE_XPT2048)
  uint16_t TPxMin = 190, TPxMax = 3660;
  uint16_t TPyMin = 350, TPyMax = 3600;
#elif defined(USE_STME610)
  uint16_t TPxMin = 250, TPxMax = 3600;
  uint16_t TPyMin = 200, TPyMax = 3800;
#endif

bool getTouch(uint16_t *px, uint16_t *py) {
  if (TP.touched()) {
    TS_Point p = TP.getPoint();
    if (p.z > 100 && p.x >= 0 && p.z <= 4095 && p.y >= 0 && p.y <= 4095) {
      //Serial.printf("x=%u,y=%u,z=%u (%u) ", p.x, p.y, p.z, TP_ROTATION);
      uint16_t x = p.x + 2, y = p.y + 2;
      if (TP_ROTATION & TPC_R) std::swap(x, y);
      if (TP_ROTATION & TPC_X) { x = 4095 - x; }
      if (TP_ROTATION & TPC_Y) { y = 4095 - y; }
      x = constrain(x, TPxMin, TPxMax);
      y = constrain(y, TPyMin, TPyMax);
      *px = map(x, TPxMin, TPxMax, 0, (tft.width()  - 1));
      *py = map(y, TPyMin, TPyMax, 0, (tft.height() - 1));
      //Serial.printf("x=%u,y=%u\n", *px, *py);
      return (true);
    } else 
      ;//Serial.printf("x=%d,y=%d,z=%d\n", p.x, p.y,p.z);
  } else return (false);
}

// ---------------------------------------------------------
bool getShutter() {
  uint16_t px, py;

  if (getTouch(&px, &py)) {
    if ( (px > Z3_px) && (py < (Z3_ph / 2)) ) {
      return(true);
    }
  }
  return(false);
}
#endif
